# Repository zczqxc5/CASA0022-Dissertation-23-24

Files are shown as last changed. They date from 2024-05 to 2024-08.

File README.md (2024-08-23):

# TinyML-Based Wearable Device for Smart Home Control
c65d1a3ddbf9a18497049976181c432

## How to use device
[Video Presentation-Yotube Link](https://youtu.be/EPODbB0qoMU)

## Project Overview

This project incorporates Tiny Machine Learning (TinyML) technology into affordable, microcontroller-based wearable devices to enable seamless and accurate smart home interactions for individuals with hearing and speech impairments. The system recognizes American Sign Language (ASL) gestures, allowing users to control smart home devices without relying on voice commands.
### Key Features:
- Gesture recognition for controlling smart home devices
- Vibration alerts for environmental sounds (e.g., door knocking)
- Real-time display of environmental data (e.g., temperature, humidity) using gestures
  
### Research Question
To what extent can the integration of TinyML technology in low-cost microcontroller-based wearable devices facilitate seamless and precise smart home operations for individuals with hearing and speech challenges?

## Table of Contents

- [Project Overview](#project-overview)
- [Hardware Used](#hardware-used)
- [Software Used](#software-used)
- [System Architecture](#system-architecture)
- [Data Collection](#data-collection)
- [Model Development](#model-development)
- [Results](#results)
- [Limitations](#limitations)
- [Future Work](#future-work)

## Hardware Used

- **Microcontroller**: Seeed Studio XIAO BLE Sense
  - ARM Cortex-M4 Processor
  - 9-axis IMU (Accelerometer, Gyroscope, Magnetometer)
  - Bluetooth 5.0 (BLE)
- **Smart Home Components**:
  - ESP32 Microcontroller (for smart home model)
  - LED lights, Servo motor, Buzzer, DHT22 Sensor (for smart home controls)
- **Wearable Device Components**:
  - Vibrating motor for feedback
  - 1.69-inch LCD IPS screen for environmental data display
  - Li-Po Battery 3.7V 140mAh



4c1fe1656bfd53e33929082f7ee5c43

## Software Used

- **Arduino IDE**: For writing and uploading code to microcontrollers.
- **Edge Impulse**: Platform used for TinyML model development. The data and model can be copied from: https://studio.edgeimpulse.com/public/405924/live
- **TensorFlow Lite**: Used to deploy the trained model on the microcontroller.
- **Fusion 360**: Used for PCB and enclosure design.

## System Architecture

The system is designed to collect gesture data from a wearable device, process it using TinyML models, and send the results to control smart home devices. The smart home devices, including lights, curtains, and speakers, are controlled based on the recognized ASL gestures.
Untitled (1)

## How to reproduced

1. Prepare hardwares and softwares from above list
2. Making PCB then conneted hardwares or connected them as circuits
3. Use Egen Impluse platform to build deployment of "Arduino Library", and import it into Arduino IDE
4. Upload code to Xiao BLE Sense/Esp32 respectively from file [Code-XiaoBLESense] /[Code-ESP32]
5. 3d print(PLA material) and laser cut(3mm wood) the enclousure from file [Enclousure]

## Data Collection

IMU data (accelerometer and gyroscope) was collected using the Seeed Studio XIAO BLE Sense to recognize 7 different ASL gestures:
- "Hello"
- "Bye"
- "Curtain"
- "Light"
- "Music"
- "Display"
- "Other"

A total of 2,149 samples were collected from 20 participants over 7 gesture categories. The data was split into 80% for training and 20% for testing.
poster

## Model Development

The TinyML model was developed using Edge Impulse and deployed on the Seeed Studio XIAO BLE Sense. The model uses the following techniques:
- **Spectral Analysis**: To extract frequency and power characteristics from IMU data.
- **Low-Pass Filter**: Applied to remove high-frequency noise.
- **Neural Network Architecture**: Designed to optimize gesture recognition with an accuracy of 98.79% during testing.

## Results

### Model Performance:
- **Testing Accuracy**: 98.79%
- **User Testing Accuracy**: 91.28%

The model demonstrated high accuracy in recognizing gestures like "Curtain," "Music," and "Bye," with over 95% accuracy. However, some gestures, such as "Light" and "Display," experienced slight confusion, which impacted real-world user testing.

### User Testing:
7 participants tested the system in a simulated smart home environment, and the overall accuracy during these tests was 91.28%. The average response time for smart home operations was 1.2 seconds.

### Confusion Matrix:


## Limitations

- **Gesture Confusion**: Similar gestures like "Light" and "Display" were sometimes confused, impacting real-world usability.
- **User Testing**: While the model performed well in controlled environments, real-world accuracy dropped to 91.28%, indicating room for improvement in diverse conditions.

## Future Work

- **Improve Gesture Recognition**: Focus on refining the recognition of similar gestures like "Light" and "Display."
- **Expand System Capabilities**: Integrate more smart home devices and explore more advanced user interfaces (e.g., haptic feedback).
- **Larger-Scale Testing**: Conduct more extensive user testing with diverse participants to improve model generalizability.

## Acknowledgements

This project was developed as part of my dissertation for the Connected Environments module at University College London. Special thanks to my advisor, Andy Hudson-Smith and all of Connected Environment tutors, for their guidance and support.

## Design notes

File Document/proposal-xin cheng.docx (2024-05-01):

Working Title

Gesture to Communicate: Bridging the Gap in Smart Homes for Individuals with Hearing and Speaking Loss

Hypothesis/Research Question

To what extent can the integration of TinyML technology in wearable watches facilitate seamless and precise smart home operations for individuals facing hearing and speech challenges?

Background / Preliminary Literature Review

The rapid increase in internet-connected smart devices has led to a paradigm shift in user interfaces, with a growing preference for voice over visual interfaces to reduce costs(Bigham et al., 2017). However, this shift presents significant accessibility challenges for the approximately 466 million people worldwide with hearing impairments, underscoring the importance of developing more inclusive smart home technologies(Kraljević et al., 2020). Recent advancements in gesture recognition, particularly through edge computing and deep learning in wearable devices, offer promising solutions to these challenges.

Gesture recognition can be categorized into two primary methods: vision-based and non-vision-based. Compared with vision-based gesture recognition, utilizing accelerometers, and incorporate Tiny Machine Learning (TinyML), offer a low-cost and seamless solution(Jalal et al., 2019; Sharma et al., 2024). This is because decentralized processing offloads data analysis to edge devices, which can reduce bandwidth requirements and latency, and also decrease the total transmission time needed for wireless devices(Coffen and Mahmud, 2021). According to Kraljević et al (2020) sensory gloves have historically dominated in terms of performance, but they often do not align with Human-Computer Interaction (HCI) principles. However, using wearable watches to capture accelerometer data provides another effective and efficient way to communicate with smart home devices. (Alemuda and Lin, 2017; Nguyen-Trong et al., 2021).

The Apollo SignSound system research offers a prototype smart home for deaf users that can collect environmental sounds and alert users to events like boiling kettles and door knocking, showcasing the potential of smart environments to improve the daily lives of hearing-impaired users(da Rosa Tavares and Victória Barbosa, 2021). On the other hand, Pothong and Turner (2020) highlight persistent challenges for living with hearing loss, including concerns over privacy and the necessity for enhanced interoperability between assistive technologies and mainstream smart home devices. However, people with hearing loss have the same abilities as everyone else and like to take advantage of the technology at their disposal.

While existing technologies have improved the quality of life for hearing-impaired individuals to some extent, limitations and challenges persist, such as the accuracy of gesture recognition, the real-time responsiveness of systems, optimization of user interaction experiences, and the interoperability and universality of smart home devices. Especially in providing seamless and precise control over smart home operations for hearing-impaired individuals, further research is needed to explore more efficient gesture recognition methods and better user experience designs.

Moreover, while smartwatches and other wearable devices have shown great potential in gesture recognition and communication devices, how they can be better integrated into smart home systems to offer more natural and intuitive control remains an open research area. Therefore, this study aims to explore a new solution by integrating edge computing models into wearable watches, to achieve precise and seamless control over smart homes, particularly for individuals facing hearing and speech challenges.

Research Design

To answer the research question, a wearable watch will be designed and produced, utilizing the nRF52840 development board to capture data from its built-in accelerometer. The nRF52840 development board is small in size, making it highly suitable for the construction of wearable watches. Additionally, it is equipped with a Bluetooth module, enabling rapid communication with smart home devices.

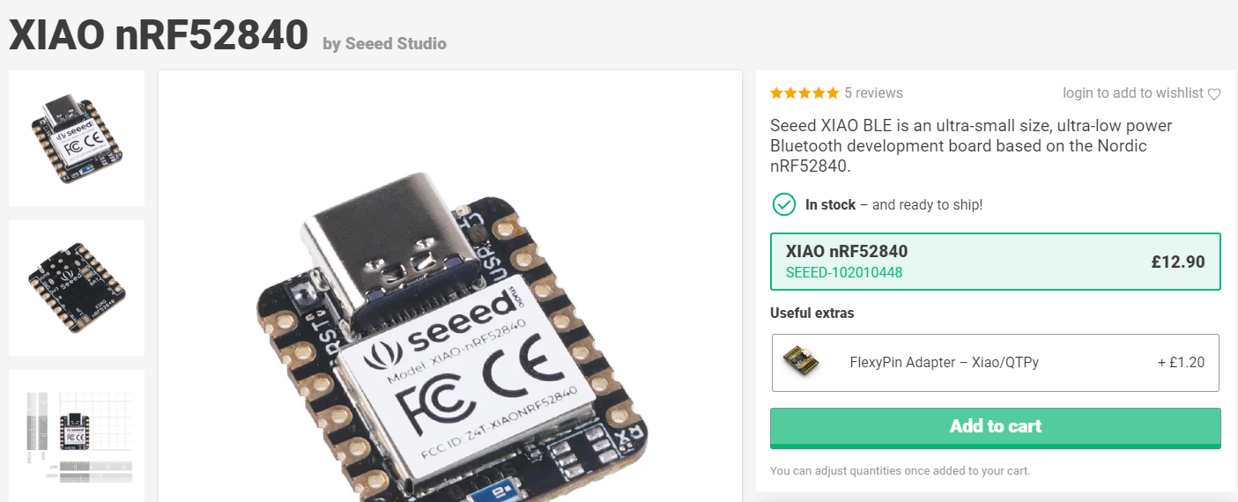
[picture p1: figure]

The gestures for controlling smart home devices will be designed based on basic sign language. Considering that sign language involves a significant amount of finger movement, and given the limitations of wearable watches in recognizing these movements, it is not my intention to recognize complete sign language. Instead, I will extract certain gesture information from sign language to design the gesture language for my system. For example, using “hello” to wake up the device, and “see you later” to turn off the device recognition.

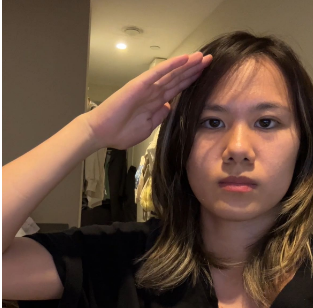
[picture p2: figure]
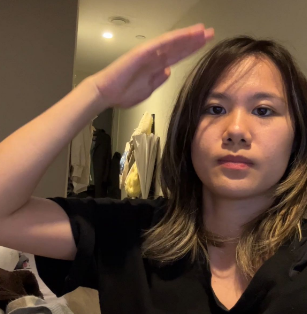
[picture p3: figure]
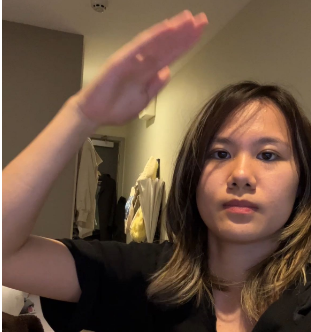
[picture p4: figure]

“hello”

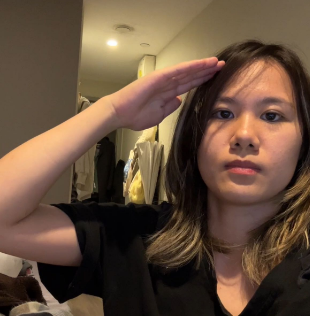
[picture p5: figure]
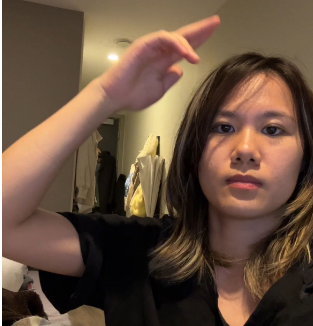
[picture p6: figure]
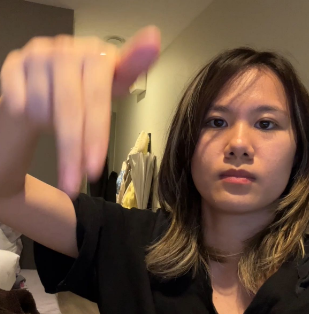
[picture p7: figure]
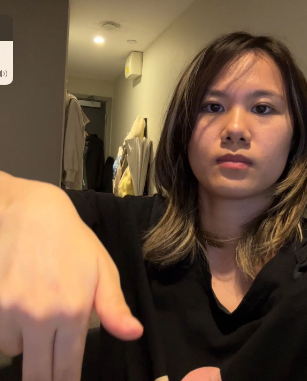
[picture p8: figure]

”see you”

Regarding deployment, I considered implementing this in a real smart home environment (referring to Home Assistant), but due to the desired exhibition effect, time constraints, and my own programming capabilities, I decided to create a scaled-down smart home model controlled by Arduino. Additionally, a watch screen will be connected to my nRF52840 development board to display certain information.

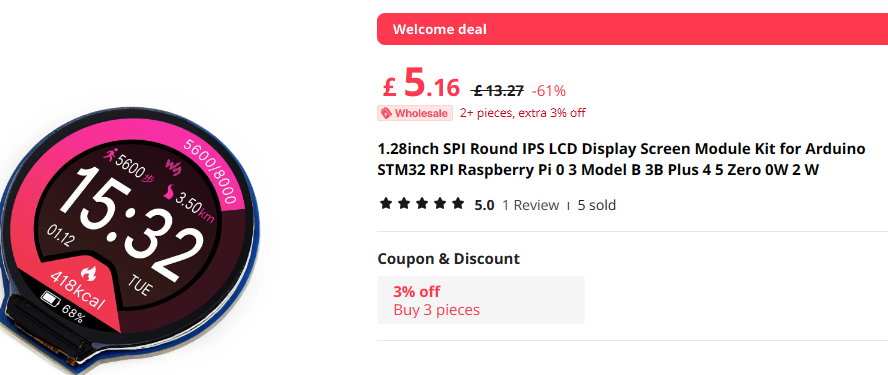
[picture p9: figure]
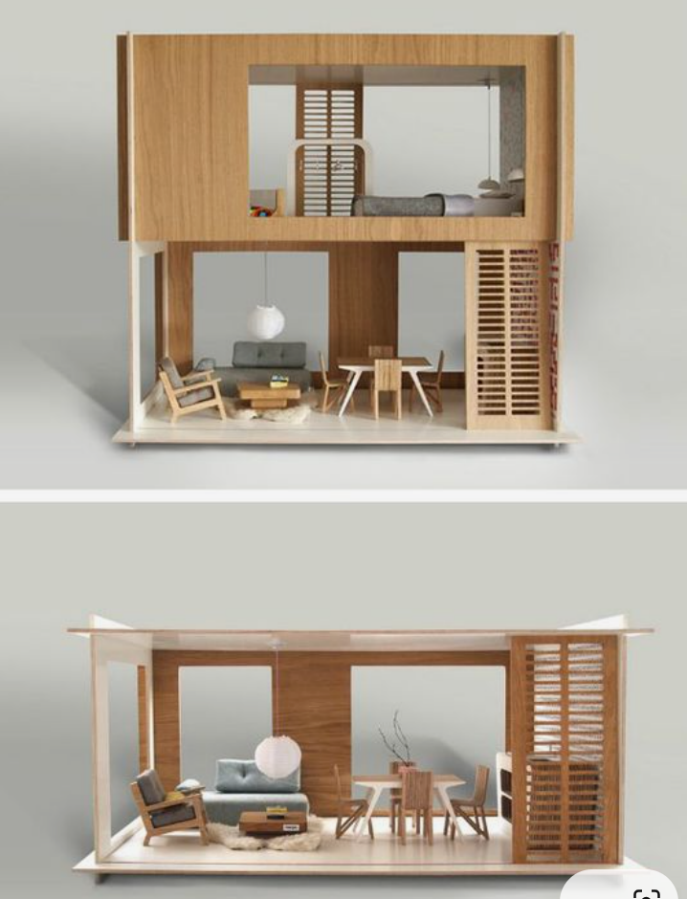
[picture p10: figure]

The smart home primarily includes sensor and actuator functions, allowing users to manipulate devices or access device information through gesture recognition. This includes functions such as opening and closing curtains, turning lights on and off, gathering environmental data, and detecting ambient sounds.

Ethics Statement

Considering ethical concerns, the study will anonymously collect gesture information to ensure it cannot be traced back to any individual. Furthermore, all data transmission and storage processes will employ encryption technology to prevent data breaches or unauthorized access. Additionally, all participants involved in the study will receive full information about the project before it begins and will have the opportunity to ask questions. Participant data will only be collected and used after obtaining explicit written consent.

Timetable

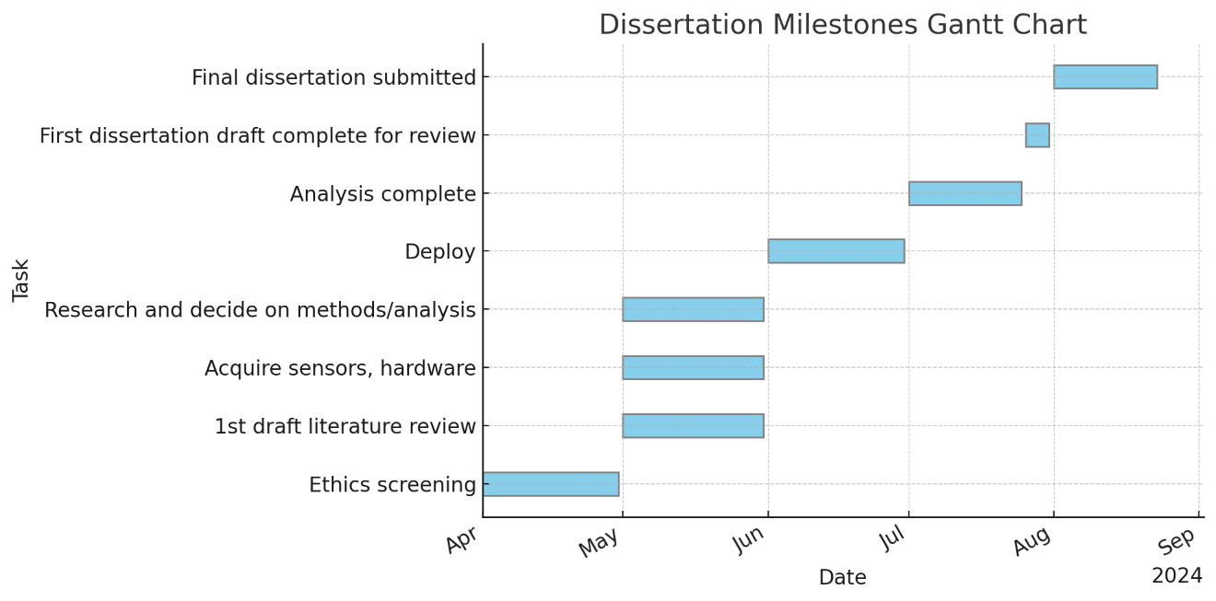
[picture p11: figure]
Output image

References

Alemuda, F., Lin, F.J., 2017. Gesture-Based Control in a Smart Home Environment, in: 2017 IEEE International Conference on Internet of Things (iThings) and IEEE Green Computing and Communications (GreenCom) and IEEE Cyber, Physical and Social Computing (CPSCom) and IEEE Smart Data (SmartData). Presented at the 2017 IEEE International Conference on Internet of Things (iThings) and IEEE Green Computing and Communications (GreenCom) and IEEE Cyber, Physical and Social Computing (CPSCom) and IEEE Smart Data (SmartData), pp. 784–791. https://doi.org/10.1109/iThings-GreenCom-CPSCom-SmartData.2017.120

Bigham, J.P., Kushalnagar, R., Huang, T.-H.K., Flores, J.P., Savage, S., 2017. On How Deaf People Might Use Speech to Control Devices, in: Proceedings of the 19th International ACM SIGACCESS Conference on Computers and Accessibility, ASSETS ’17. Association for Computing Machinery, New York, NY, USA, pp. 383–384. https://doi.org/10.1145/3132525.3134821

Coffen, B., Mahmud, Md.S., 2021. TinyDL: Edge Computing and Deep Learning Based Real-time Hand Gesture Recognition Using Wearable Sensor, in: 2020 IEEE International Conference on E-Health Networking, Application & Services (HEALTHCOM). Presented at the 2020 IEEE International Conference on E-health Networking, Application & Services (HEALTHCOM), pp. 1–6. https://doi.org/10.1109/HEALTHCOM49281.2021.9399005

da Rosa Tavares, J.E., Victória Barbosa, J.L., 2021. Apollo SignSound: an intelligent system applied to ubiquitous healthcare of deaf people. J. Reliab. Intell. Environ. 7, 157–170. https://doi.org/10.1007/s40860-020-00119-w

Jalal, A., Quaid, M.A.K., Sidduqi, M.A., 2019. A Triaxial Acceleration-based Human Motion Detection for Ambient Smart Home System, in: 2019 16th International Bhurban Conference on Applied Sciences and Technology (IBCAST). Presented at the 2019 16th International Bhurban Conference on Applied Sciences and Technology (IBCAST), pp. 353–358. https://doi.org/10.1109/IBCAST.2019.8667183

Kraljević, L., Russo, M., Pauković, M., Šarić, M., 2020. A Dynamic Gesture Recognition Interface for Smart Home Control based on Croatian Sign Language. Appl. Sci. 10, 2300. https://doi.org/10.3390/app10072300

Nguyen-Trong, K., Vu, H.N., Trung, N.N., Pham, C., 2021. Gesture Recognition Using Wearable Sensors With Bi-Long Short-Term Memory Convolutional Neural Networks. IEEE Sens. J. 21, 15065–15079. https://doi.org/10.1109/JSEN.2021.3074642

Pothong, K., Turner, S., 2020. Living with Hearing Loss in a Connected Home: White Paper (Report), UCL Department of Science, Technology, Engineering and Public Policy (STEaPP): London, UK. UCL Department of Science, Technology, Engineering and Public Policy (STEaPP), London, UK.

Sharma, S., Gupta, R., Kumar, A., 2024. A TinyML solution for an IoT-based communication device for hearing impaired. Expert Syst. Appl. 246, 123147. https://doi.org/10.1016/j.eswa.2024.123147

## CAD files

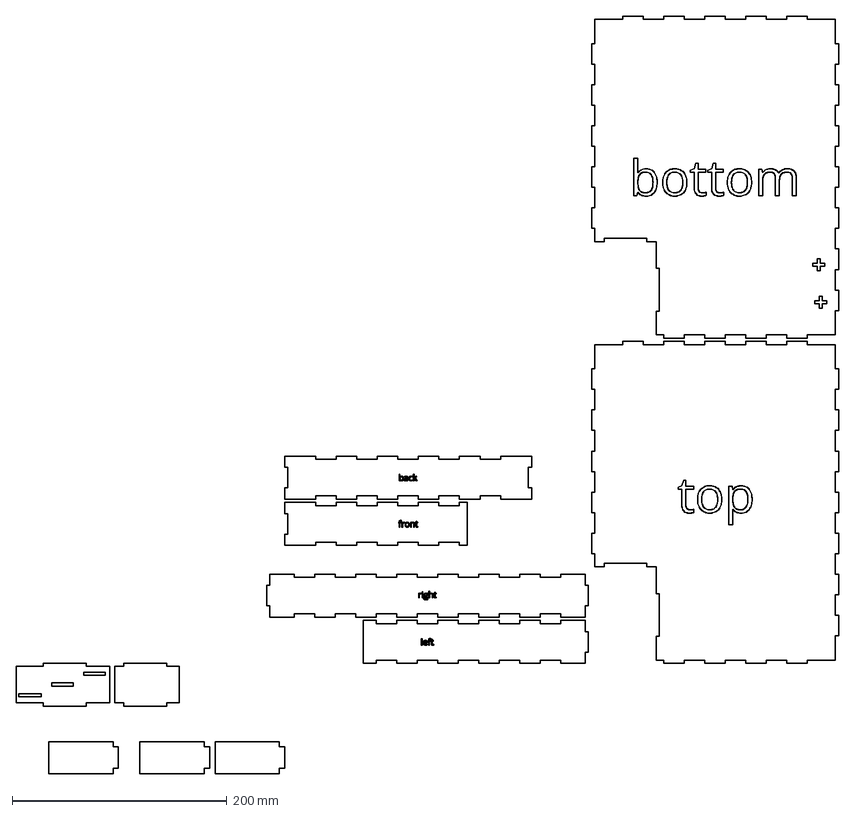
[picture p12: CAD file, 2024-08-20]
Enclousure/XinCheng-bottom box.dxf
766.0 x 706.0 mm

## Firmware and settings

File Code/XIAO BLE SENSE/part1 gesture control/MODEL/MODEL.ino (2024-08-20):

/*
This code initializes and operates on XIAO BLE SENSE with sensors and Bluetooth Low Energy (BLE) communication. 
It configures an Inertial Measurement Unit (IMU) for reading accelerometer and gyroscope data, processes these sensor inputs, 
and uses a neural network for classification. The results are sent via BLE and displayed on a screen, with the system 
responding to specific commands like "hello" and "bye" by controlling a motor and updating the display.
*/

#include <fonts.h>
#include <st7789v2.h>

#include <new_inferencing.h>
#include <Wire.h>
#include <LSM6DS3.h>

#include "SPI.h"
#include "seeed.h"
#include <ArduinoBLE.h>

#define LABEL_COUNT 7
#define MOTOR_PIN 2
const char *labels[LABEL_COUNT] = { "bye", "cuetain", "display", "hello", "light", "music", "other" };
bool isActive = false;    
int getLabelId(const char *label) {
  for (int i = 0; i < LABEL_COUNT; i++) {
    if (strcmp(labels[i], label) == 0) {
      return i;
    }
  }
  return -1;
}


LSM6DS3 myIMU(I2C_MODE, 0x6A);

BLEService ledService("19b10000-e8f2-537e-4f6c-d104768a1214");

BLEIntCharacteristic labelCharacteristic("19b10002-e8f2-537e-4f6c-d104768a1214", BLERead | BLEWrite);

enum sensor_status {
  NOT_USED = -1,
  NOT_INIT,
  INIT,
  SAMPLED
};

typedef struct {
  const char *name;
  float *value;
  uint8_t (*poll_sensor)(void);
  bool (*init_sensor)(void);
  sensor_status status;
} eiSensors;

#define CONVERT_G_TO_MS2 9.80665f
#define DEG_TO_RAD 0.0174533f
#define N_SENSORS 6
#define EI_CLASSIFIER_FUSION_AXES_STRING "accX + accY + accZ + gyrX + gyrY + gyrZ"

float data[N_SENSORS];
int8_t fusion_sensors[N_SENSORS];
int fusion_ix = 0;

float max_value = 0.0;
const char *max_label = "bye";
const char *previous_label = "";
unsigned long previousMillis = 0;
unsigned long previousSampleMillis = 0;
unsigned long previousDisplayMillis = 0;
const unsigned long sampleInterval = 1000;
const unsigned long displayInterval = 1000;



st7789v2 Display;

bool init_IMU(void) {
  static bool init_status = false;
  if (!init_status) {
    init_status = (myIMU.begin() == 0);
    if (init_status) {
      Serial.println("IMU initialized successfully");
    } else {
      Serial.println("IMU initialization failed");
    }
  }
  return init_status;
}

uint8_t poll_acc(void) {
  data[0] = myIMU.readFloatAccelX() * CONVERT_G_TO_MS2;
  data[1] = myIMU.readFloatAccelY() * CONVERT_G_TO_MS2;
  data[2] = myIMU.readFloatAccelZ() * CONVERT_G_TO_MS2;
  return 0;
}

uint8_t poll_gyr(void) {
  data[3] = myIMU.readFloatGyroX() * DEG_TO_RAD;
  data[4] = myIMU.readFloatGyroY() * DEG_TO_RAD;
  data[5] = myIMU.readFloatGyroZ() * DEG_TO_RAD;
  return 0;
}

eiSensors sensors[] = {
  { "accX", &data[0], &poll_acc, &init_IMU, NOT_USED },
  { "accY", &data[1], &poll_acc, &init_IMU, NOT_USED },
  { "accZ", &data[2], &poll_acc, &init_IMU, NOT_USED },
  { "gyrX", &data[3], &poll_gyr, &init_IMU, NOT_USED },
  { "gyrY", &data[4], &poll_gyr, &init_IMU, NOT_USED },
  { "gyrZ", &data[5], &poll_gyr, &init_IMU, NOT_USED },
};

static int8_t ei_find_axis(char *axis_name) {
  for (int ix = 0; ix < N_SENSORS; ix++) {
    if (strstr(axis_name, sensors[ix].name)) {
      return ix;
    }
  }
  return -1;
}

static bool ei_connect_fusion_list(const char *input_list) {
  char *buff;
  bool is_fusion = false;

  char *input_string = (char *)ei_malloc(strlen(input_list) + 1);
  if (input_string == NULL) {
    Serial.println("Error allocating memory for input_string");
    return false;
  }
  memset(input_string, 0, strlen(input_list) + 1);
  strncpy(input_string, input_list, strlen(input_list));

  memset(fusion_sensors, 0, N_SENSORS);
  fusion_ix = 0;

  buff = strtok(input_string, "+");
  while (buff != NULL) {
    int8_t found_axis = ei_find_axis(buff);
    Serial.print("Checking axis: ");
    Serial.println(buff);

    if (found_axis >= 0) {
      if (fusion_ix < N_SENSORS) {
        fusion_sensors[fusion_ix++] = found_axis;
        sensors[found_axis].status = NOT_INIT;
      }
      is_fusion = true;
      Serial.print("Found axis: ");
      Serial.println(sensors[found_axis].name);
    } else {
      Serial.print("Axis not found: ");
      Serial.println(buff);
    }

    buff = strtok(NULL, "+ ");
  }

  ei_free(input_string);

  return is_fusion;
}

void setup() {
  pinMode(MOTOR_PIN, OUTPUT);
  digitalWrite(MOTOR_PIN, LOW);  
  Serial.begin(9600);

  if (!BLE.begin()) {
    Serial.println("starting Bluetooth® Low Energy module failed!");
    while (1)
      ;
  }

  BLE.setAdvertisingInterval(32);
  BLE.setConnectionInterval(6, 12);

  Serial.println("Bluetooth® Low Energy module initialized.");

  BLE.setLocalName("XIAO");
  BLE.setAdvertisedService(ledService);

  ledService.addCharacteristic(labelCharacteristic);
  BLE.addService(ledService);

  labelCharacteristic.writeValue(0);
  BLE.advertise();

  Serial.println("Bluetooth device active, waiting for connections...");

  Wire.begin();

  Serial.println("Starting initialization...");

  Serial.print("Required sensors: ");
  Serial.println(EI_CLASSIFIER_FUSION_AXES_STRING);

  if (!ei_connect_fusion_list(EI_CLASSIFIER_FUSION_AXES_STRING)) {
    Serial.println("ERR: Errors in sensor list detected");
    return;
  }

  for (int i = 0; i < fusion_ix; i++) {
    if (sensors[fusion_sensors[i]].status == NOT_INIT) {
      sensors[fusion_sensors[i]].status = (sensor_status)sensors[fusion_sensors[i]].init_sensor();
      if (!sensors[fusion_sensors[i]].status) {
        Serial.print(sensors[fusion_sensors[i]].name);
        Serial.println(" axis sensor initialization failed.");
      } else {
        Serial.print(sensors[fusion_sensors[i]].name);
        Serial.println(" axis sensor initialization successful.");
      }
    }
  }

  Display.SetRotate(180);
  Display.Init();
  Display.SetBacklight(100);
  Display.Clear(WHITE);
  display();

}

void loop() {
  BLEDevice central = BLE.central();

  if (central) {
    if (central.connected()) {
      unsigned long currentMillis = millis();
      if (currentMillis - previousMillis >= 2500) {
        previousMillis = currentMillis;
        int labelId = getLabelId(max_label);
        if (labelId != -1) {
          labelCharacteristic.writeValue(labelId);
          Serial.print("Sent via Bluetooth: ");
          Serial.println(labelId);
        }
      }
    } else {
      Serial.print("Disconnected from central: ");
      Serial.println(central.address());
    }
  }

  unsigned long currentSampleMillis = millis();
  if (currentSampleMillis - previousSampleMillis >= sampleInterval) {
    previousSampleMillis = currentSampleMillis;

    if (EI_CLASSIFIER_RAW_SAMPLES_PER_FRAME != fusion_ix) {
      Serial.print("ERR: Sensors don't match the sensors required in the model\n");
      Serial.print("Following sensors are required: ");
      Serial.println(EI_CLASSIFIER_FUSION_AXES_STRING);
      return;
    }

    Serial.println("Sampling...");

    float buffer[EI_CLASSIFIER_DSP_INPUT_FRAME_SIZE] = { 0 };

    for (size_t ix = 0; ix < EI_CLASSIFIER_DSP_INPUT_FRAME_SIZE; ix += EI_CLASSIFIER_RAW_SAMPLES_PER_FRAME) {
      int64_t next_tick = (int64_t)micros() + ((int64_t)EI_CLASSIFIER_INTERVAL_MS * 1000);

      for (int i = 0; i < fusion_ix; i++) {
        if (sensors[fusion_sensors[i]].status == INIT) {
          sensors[fusion_sensors[i]].poll_sensor();
          sensors[fusion_sensors[i]].status = SAMPLED;
        }
        if (sensors[fusion_sensors[i]].status == SAMPLED) {
          buffer[ix + i] = *sensors[fusion_sensors[i]].value;
          sensors[fusion_sensors[i]].status = INIT;
        }
      }

      int64_t wait_time = next_tick - (int64_t)micros();
      if (wait_time > 0) {
        delayMicroseconds(wait_time);
      }

      BLE.poll();
    }

    signal_t signal;
    int err = numpy::signal_from_buffer(buffer, EI_CLASSIFIER_DSP_INPUT_FRAME_SIZE, &signal);
    if (err != 0) {
      Serial.print("ERR: ");
      Serial.println(err);
      return;
    }

    ei_impulse_result_t result = { 0 };
    err = run_classifier(&signal, &result, false);
    if (err != EI_IMPULSE_OK) {
      Serial.print("ERR: ");
      Serial.println(err);
      return;
    }

    Serial.print("Predictions (DSP: ");
    Serial.print(result.timing.dsp);
    Serial.print(" ms., Classification: ");
    Serial.print(result.timing.classification);
    Serial.print(" ms., Anomaly: ");
    Serial.print(result.timing.anomaly);
    Serial.println(" ms.):");
    update_max_probability_label(result);

    for (size_t ix = 0; ix < EI_CLASSIFIER_LABEL_COUNT; ix++) {
      Serial.print(result.classification[ix].label);
      Serial.print(": ");
      Serial.println(result.classification[ix].value);
    }

#if EI_CLASSIFIER_HAS_ANOMALY == 1
    Serial.print("    anomaly score: ");
    Serial.println(result.anomaly);
#endif
  }

  unsigned long currentDisplayMillis = millis();
  if (currentDisplayMillis - previousDisplayMillis >= displayInterval && strcmp(max_label, previous_label) != 0) {
    previousDisplayMillis = currentDisplayMillis;
    previous_label = max_label;
  }
}

void update_max_probability_label(ei_impulse_result_t result) {
  max_value = 0.0;
  max_label = "bye";

  for (size_t ix = 0; ix < EI_CLASSIFIER_LABEL_COUNT; ix++) {
    if (result.classification[ix].value > max_value) {
      max_value = result.classification[ix].value;
      max_label = result.classification[ix].label;
    }
  }

  if (max_label != nullptr) {
    Serial.print("Max label: ");
    Serial.println(max_label);
    if (previous_label == nullptr || strcmp(previous_label, max_label) != 0) {

      if (strcmp(max_label, "hello") == 0) {
        vibrateMotor(true);
        delay(200);
        vibrateMotor(false);
        delay(200);
        isActive = true;
        updateDisplay("Ready!       "); 
      } else if (strcmp(max_label, "bye") == 0) {
        vibrateMotor(true);
        delay(200);
        vibrateMotor(false);
        delay(200);
        vibrateMotor(true);
        delay(200);
        vibrateMotor(false);
        delay(200);
        isActive = false;
        updateDisplay("Byebye!");  
        updatevalue("       ");
        Display.DrawString_EN(30, 125, "Silent Home ", &Font20, WHITE, BLACK);
      }
      if (isActive) {
        if (strcmp(max_label, "light") == 0) {
          updatevalue("light  ");
        }else if (strcmp(max_label, "cuetain") == 0){
          updatevalue("curtain");
        }else if (strcmp(max_label, "display") == 0){
          updatevalue("display");
          Display.DrawString_EN(30, 125, "Tem:22 Hum:46%", &Font16, WHITE, BLACK);
        }else if (strcmp(max_label, "music") == 0){
          updatevalue("music  ");
        }
      }
      previous_label = max_label;
    }
  } else {
    previous_label = nullptr;
  }
}


void updateDisplay(const char *label) {
  int x = (240 - strlen(label) * 10) / 2;
  int y = (240 - 20) / 2;
  Display.DrawString_EN(30, 100, label, &Font20, WHITE, BLACK);
}
void updatevalue(const char *label) {
  Display.DrawString_EN(120, 100, label, &Font20, WHITE, BLACK);
}
void vibrateMotor(bool on) {
  if (on) {
    Serial.println("Motor ON command sent");
    digitalWrite(MOTOR_PIN, HIGH);
    delay(500);
  } else {
    Serial.println("Motor OFF command sent");
    digitalWrite(MOTOR_PIN, LOW);
    delay(500);
  }
}

void display() {
  updateDisplay("Hi!");
  Display.DrawLine(15, 65, 65, 65, MAGENTA, DOT_PIXEL_2X2, LINE_STYLE_SOLID);
  Display.DrawLine(15, 70, 80, 70, MAGENTA, DOT_PIXEL_2X2, LINE_STYLE_SOLID);

  Display.DrawRectangle(15, 80, 225, 150, GRAY, DOT_PIXEL_2X2, DRAW_FILL_EMPTY);

  Display.DrawCircle(10, 10, 25, MAGENTA, DOT_PIXEL_2X2, DRAW_FILL_EMPTY);
  Display.DrawCircle(10, 10, 20, GRAYBLUE, DOT_PIXEL_2X2, DRAW_FILL_EMPTY);
  Display.DrawCircle(10, 10, 15, MAGENTA, DOT_PIXEL_2X2, DRAW_FILL_EMPTY);
  Display.DrawCircle(10, 10, 10, GRAYBLUE, DOT_PIXEL_2X2, DRAW_FILL_FULL);

  Display.DrawCircle(230, 10, 25, MAGENTA, DOT_PIXEL_2X2, DRAW_FILL_EMPTY);
  Display.DrawCircle(230, 10, 20, GRAYBLUE, DOT_PIXEL_2X2, DRAW_FILL_EMPTY);
  Display.DrawCircle(230, 10, 15, MAGENTA, DOT_PIXEL_2X2, DRAW_FILL_EMPTY);
  Display.DrawCircle(230, 10, 10, GRAYBLUE, DOT_PIXEL_2X2, DRAW_FILL_FULL);

  Display.DrawCircle(10, 270, 25, MAGENTA, DOT_PIXEL_2X2, DRAW_FILL_EMPTY);
  Display.DrawCircle(10, 270, 20, GRAYBLUE, DOT_PIXEL_2X2, DRAW_FILL_EMPTY);
  Display.DrawCircle(10, 270, 15, MAGENTA, DOT_PIXEL_2X2, DRAW_FILL_EMPTY);
  Display.DrawCircle(10, 270, 10, GRAYBLUE, DOT_PIXEL_2X2, DRAW_FILL_FULL);

  Display.DrawCircle(230, 270, 25, MAGENTA, DOT_PIXEL_2X2, DRAW_FILL_EMPTY);
  Display.DrawCircle(230, 270, 20, GRAYBLUE, DOT_PIXEL_2X2, DRAW_FILL_EMPTY);
  Display.DrawCircle(230, 270, 15, MAGENTA, DOT_PIXEL_2X2, DRAW_FILL_EMPTY);
  Display.DrawCircle(230, 270, 10, GRAYBLUE, DOT_PIXEL_2X2, DRAW_FILL_FULL);

  Display.DrawLine(195, 160, 225, 160, GRAYBLUE, DOT_PIXEL_2X2, LINE_STYLE_SOLID);
  Display.DrawLine(175, 165, 225, 165, GRAYBLUE, DOT_PIXEL_2X2, LINE_STYLE_SOLID);
  Display.DrawString_EN(30, 125, "Silent Home", &Font20, WHITE, BLACK);
  Display.DrawString_EN(20, 180, "By: Xin Cheng", &Font20, WHITE, BLACK);
}

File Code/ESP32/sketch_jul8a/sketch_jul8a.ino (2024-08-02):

#include <BLEDevice.h>
#include <BLEUtils.h>
#include <BLEScan.h>
#include <BLEAdvertisedDevice.h>
#include <BLEServer.h>
#include <ESP32Servo.h>
#include "DHT.h"

#define DHTPIN 21
#define DHTTYPE DHT22
DHT dht(DHTPIN, DHTTYPE);
Servo myServo;
int servoPosition = 0;
String lastValue = "";
int ledPin = 19;
bool ledState = false;

// 按键和蜂鸣器的引脚定义
const int switchPin = 22;  // 按键开关连接引脚
const int buzzer = 15;     // 蜂鸣器连接引脚
bool isActive = false;     // 增加状态变量，初始为 false

static BLEUUID serviceUUID("19b10000-e8f2-537e-4f6c-d104768a1214");
static BLEUUID charUUID("19b10002-e8f2-537e-4f6c-d104768a1214");
static BLEUUID temperatureCharUUID("19b10003-e8f2-537e-4f6c-d104768a1214");
static BLEUUID humidityCharUUID("19b10004-e8f2-537e-4f6c-d104768a1214");
static BLEUUID buttonCharUUID("19b10005-e8f2-537e-4f6c-d104768a1214");  // 新增按钮特征值UUID
BLECharacteristic* pButtonCharacteristic = NULL;                        // 新增按钮特征值变量

BLEServer* pServer = NULL;
BLECharacteristic* pCharacteristic = NULL;
BLECharacteristic* pTemperatureCharacteristic = NULL;
BLECharacteristic* pHumidityCharacteristic = NULL;

BLEClient* pClient;
BLEScan* pBLEScan;
bool doConnect = false;
bool connected = false;
bool doScan = false;
BLERemoteCharacteristic* pRemoteCharacteristic;
BLEAdvertisedDevice* myDevice;
const char* labels[] = { "bye", "curtain", "display", "hello", "light", "music", "other" };

unsigned long previousMillis = 0;
const long interval = 5000;


unsigned long noteDelay = 0;
int length;



bool isPlaying = false;
unsigned long noteStartTime = 0;
int currentNote = 0;
bool buttonPressed = false;

class MyClientCallback : public BLEClientCallbacks {
  void onConnect(BLEClient* pclient) {}

  void onDisconnect(BLEClient* pclient) {
    connected = false;
    Serial.println("Disconnected");
  }
};

bool connectToServer() {
  Serial.print("Forming a connection to ");
  Serial.println(myDevice->getAddress().toString().c_str());

  pClient = BLEDevice::createClient();
  Serial.println(" - Created client");

  pClient->setClientCallbacks(new MyClientCallback());

  pClient->connect(myDevice);
  Serial.println(" - Connected to server");

  BLERemoteService* pRemoteService = pClient->getService(serviceUUID);
  if (pRemoteService == nullptr) {
    Serial.print("Failed to find our service UUID: ");
    Serial.println(serviceUUID.toString().c_str());
    pClient->disconnect();
    return false;
  }
  Serial.println(" - Found our service");

  pRemoteCharacteristic = pRemoteService->getCharacteristic(charUUID);
  if (pRemoteCharacteristic == nullptr) {
    Serial.print("Failed to find our characteristic UUID: ");
    Serial.println(charUUID.toString().c_str());
    pClient->disconnect();
    return false;
  }
  Serial.println(" - Found our characteristic");

  return true;
}

class MyAdvertisedDeviceCallbacks : public BLEAdvertisedDeviceCallbacks {
  void onResult(BLEAdvertisedDevice advertisedDevice) {
    Serial.print("Advertised Device Found: ");
    Serial.println(advertisedDevice.toString().c_str());

    if (advertisedDevice.haveServiceUUID() && advertisedDevice.isAdvertisingService(serviceUUID)) {
      Serial.print("Found our device!  address: ");
      Serial.println(advertisedDevice.getAddress().toString().c_str());
      BLEDevice::getScan()->stop();
      myDevice = new BLEAdvertisedDevice(advertisedDevice);
      doConnect = true;
      doScan = true;
    }
  }
};

class MyServerCallbacks : public BLEServerCallbacks {
  void onConnect(BLEServer* pServer) {
    Serial.println("Peripheral connected");
  }

  void onDisconnect(BLEServer* pServer) {
    Serial.println("Peripheral disconnected");
  }
};

void setup() {

  myServo.attach(18);
  Serial.begin(115200);
  BLEDevice::init("");
  dht.begin();
  pinMode(ledPin, OUTPUT);
  pinMode(switchPin, INPUT_PULLUP);  // 设置按键引脚为输入模式并启用内部上拉电阻
  pinMode(buzzer, OUTPUT);           // 初始化蜂鸣器引脚为输出模式

  initBLEScan();
  initBLEServer();
}

void loop() {
  unsigned long currentMillis = millis();

  if (currentMillis - previousMillis >= interval) {
    previousMillis = currentMillis;
    readData();
  }
  if (doConnect) {
    if (connectToServer()) {
      Serial.println("We are now connected to the BLE Server.");
      connected = true;
    } else {
      Serial.println("We have failed to connect to the server; there is nothing more we will do.");
    }
    doConnect = false;
  }

  if (connected) {
    if (pRemoteCharacteristic->canRead()) {
      String value = pRemoteCharacteristic->readValue();

      Serial.print("Raw value read from characteristic: ");
      for (size_t i = 0; i < value.length(); i++) {
        Serial.print((int)value[i]);
        Serial.print(" ");
      }
      Serial.println();

      if (value.length() >= 1) {
        int intValue = (uint8_t)value[0];
        Serial.print("Parsed int value: ");
        Serial.println(intValue);

        if (intValue >= 0 && intValue < 7) {
          Serial.print("Switch characteristic value: ");
          Serial.println(labels[intValue]);
          handleCharacteristicValue(labels[intValue]);
        } else {
          Serial.println("Failed to read switch characteristic value!");
        }
      } else {
        Serial.println("Unexpected length of value read from characteristic!");
      }

      Serial.print("Characteristic UUID: ");
      Serial.println(charUUID.toString().c_str());
    }
  } else if (doScan) {
    BLEDevice::getScan()->start(0);
  }

  checkButton();

  delay(1000);
}

void handleCharacteristicValue(const String& value) {
  Serial.print("Handling value: ");
  Serial.println(value);

  if (value != lastValue) {

    lastValue = value;
    if (value == "hello") {
      isActive = true;  // 识别到 "hello"，激活处理
      Serial.println("System activated by 'hello'.");
    } else if (value == "bye") {
      isActive = false;  // 识别到 "bye"，停止处理
      Serial.println("System deactivated by 'bye'.");
    }
    if (isActive) {

      if (value == "curtain") {
        toggleCurtain();
      } else if (value == "light") {
        toggleLed();
      } else if (value == "music") {
        togmusic();
      } else {
        Serial.println("System is not active. Ignoring commands.");
      }

    } else {
      Serial.println("Value is the same as the last one, no action taken.");
    }
  }
}

void toggleCurtain() {
  if (servoPosition == 0) {
    myServo.write(180);
    servoPosition = 1;
  } else {
    myServo.write(0);
    servoPosition = 0;
  }
  Serial.println("Toggling Curtain...");
}

void toggleLed() {
  ledState = !ledState;
  digitalWrite(ledPin, ledState ? HIGH : LOW);
  Serial.println("Toggling LED...");
}
void togmusic() {
  ledState = !ledState;
  buzz();
  buzz();
}
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

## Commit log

2024-07-26 add led
2024-08-01 add motor
